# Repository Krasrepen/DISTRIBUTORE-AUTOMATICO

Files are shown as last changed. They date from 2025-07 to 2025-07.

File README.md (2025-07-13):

Distributore Automatico Intelligente - ESP32

📝 Descrizione del Progetto

Sistema automatizzato per la gestione e distribuzione di componenti industriali con controllo accessi RFID, monitoraggio inventario in tempo reale e integrazione Power Apps.

🎯 Caratteristiche Principali

Autenticazione RFID: Accesso controllato tramite badge personalizzati
Gestione Inventario: Tracciamento automatico componenti con celle di carico
Interfaccia Touch: Display Nextion 3.5" per controllo intuitivo
Automazione Cassetti: Apertura/chiusura motorizzata con stepper motors
Cloud Integration: Sincronizzazione dati con Microsoft Power Apps
Operazioni Multiple: Prelievo, rientro, rifornimento e gestione manuale

🛠️ Hardware Utilizzato
ESP32 DevKit V1
Display Nextion NX4832K035_011
RFID Reader RC522
2x NEMA 17 + TB6600
4x Celle di carico + HX711

📦 Prodotti Gestiti

Cassetto A: Rondelle (peso unitario: 13g)
Cassetto B: Viti M8 (peso unitario: 29g)

🚀 Funzionalità del Sistema
1. Autenticazione e Sicurezza

Badge RFID univoci per ogni utente autorizzato
Timeout automatico sessioni (2 minuti)
Controllo accessi centralizzato

2. Operazioni Supportate

PRELIEVO: Ritiro componenti con aggiornamento automatico inventario
RIENTRO: Restituzione componenti precedentemente prelevati
RIFORNIMENTO: Aggiunta nuovi stock al magazzino
CHIUSURA MANUALE: Controllo manuale apertura cassetti

3. Monitoraggio Intelligente

Conteggio automatico tramite peso (precisione ±1 pezzo)
Calcolo quantità disponibili in tempo reale
Soglie minime personalizzabili per ogni prodotto

4. Integrazione Cloud

Sincronizzazione bidirezionale con Power Apps
Tracciabilità completa operazioni (chi, cosa, quando)
Dashboard analytics e reporting

📋 Schema Database Power Apps
Tabelle Principali:

Componenti: Anagrafica prodotti e quantità
Utenti: Gestione badge e autorizzazioni
Prelievo: Log operazioni di ritiro
Rientro: Log operazioni di restituzione
Rifornimento: Log operazioni di ricarica stock
Fornitori: Anagrafica fornitori componenti

🔧 Setup e Installazione
Prerequisiti

Arduino IDE 1.8.19+
Librerie: MFRC522, HX711, WiFi, HTTPClient, ArduinoJson
Account Microsoft Power Platform

Configurazione Hardware

Collegare componenti secondo pinout fornito
Calibrare celle di carico per ogni cassetto
Configurare display Nextion con file HMI

Configurazione Software

Compilare e caricare sketch Arduino
Configurare credenziali WiFi nel codice
Impostare webhook Power Automate
Registrare badge RFID utenti autorizzati

📊 Pinout ESP32

// RFID RC522
RST: 15, IRQ: 2, MISO: 4, SCK: 17, MOSI: 16, SS: 5

// MOTORI STEPPER  
Motore A: Enable=18, PUL=19, Dir=21
Motore B: Enable=22, PUL=23, Dir=32

// DISPLAY NEXTION
RX=35, TX=14

// CELLE DI CARICO
Cassetto A: DT=33, SCK=25  
Cassetto B: DT=26, SCK=27

🎮 Interfaccia Utente
Flusso Operativo:

Schermata Benvenuto: Richiesta badge RFID
Menu Operazioni: Selezione tipo operazione
Selezione Prodotto: Scelta componente da gestire
Operazione in Corso: Monitoraggio real-time peso/quantità
Conferma: Completamento e aggiornamento inventario

Indicatori Stato:

🟢 LED Verde: Utente autenticato
🔵 LED Blu: Connessione WiFi attiva
📊 Progress Bar: Quantità disponibili (0-30 pezzi)
⚖️ Display Peso: Peso attuale cassetto (±0.1g)

💡 Applicazioni Pratiche

Magazzini Industriali: Gestione componenti elettronici/meccanici
Laboratori R&D: Controllo materiali e strumentazione
Officine Meccaniche: Distribuzione utensili e ricambi
Ambiente Produttivo: Tracciabilità materiali per qualità

🛡️ Sicurezza e Affidabilità

Calibrazione automatica celle di carico con backup EEPROM
Gestione errori e valori anomali sensori
Retry automatico comunicazioni Power Apps
Protezione da sovraccarichi motori

📈 Vantaggi Business

Riduzione Sprechi: Tracciabilità completa prelievi
Ottimizzazione Stock: Monitoraggio automatico soglie minime
Controllo Accessi: Solo personale autorizzato
Audit Trail: Log completo per conformità ISO
ROI Rapido: Automazione processo manuale

🔮 Sviluppi Futuri

 Supporto multi-cassetto (espandibile a 8 cassetti)
 App mobile companion per gestione remota
 Integrazione bilancia di precisione esterna
 Sistema di backup locale su SD card
 Notifiche push per soglie minime raggiunte

📞 Supporto
Per questioni tecniche o richieste di personalizzazione, contattare il team di sviluppo.

Versione: 2.0
Ultimo aggiornamento: Luglio 2025
Licenza: ITS Academy Udine
Autore: Michele Zago
Email: zago.michele2002@gmail.com

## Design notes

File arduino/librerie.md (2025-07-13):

1. MFRC522 (Lettore RFID)

Versione: 1.4.10 o superiore
Autore: GithubCommunity
Scopo: Gestione lettore RFID RC522
Installazione: Library Manager → Cerca "MFRC522"

2. HX711 (Celle di carico)

Versione: 0.7.5 o superiore
Autore: Rob Tillaart
Scopo: Interfaccia con amplificatori celle di carico
Installazione: Library Manager → Cerca "HX711 Arduino Library"

3. ArduinoJson (Gestione JSON)

Versione: 6.19.4 o superiore
Autore: Benoit Blanchon
Scopo: Parsing/creazione messaggi JSON per Power Apps
Installazione: Library Manager → Cerca "ArduinoJson"

4. WiFi (Connettività)

Versione: Inclusa in ESP32 Core
Scopo: Connessione WiFi per comunicazione Power Apps
Installazione: ✅ Automatica con ESP32 board package

5. HTTPClient (Richieste HTTP)

Versione: Inclusa in ESP32 Core
Scopo: Invio webhook a Power Automate
Installazione: ✅ Automatica con ESP32 board package

6. SPI (Comunicazione seriale)

Versione: Inclusa in Arduino Core
Scopo: Comunicazione con RFID RC522
Installazione: ✅ Automatica

7. EEPROM (Memoria permanente)

Versione: Inclusa in ESP32 Core
Scopo: Salvataggio fattori calibrazione celle
Installazione: ✅ Automatica con ESP32 board package

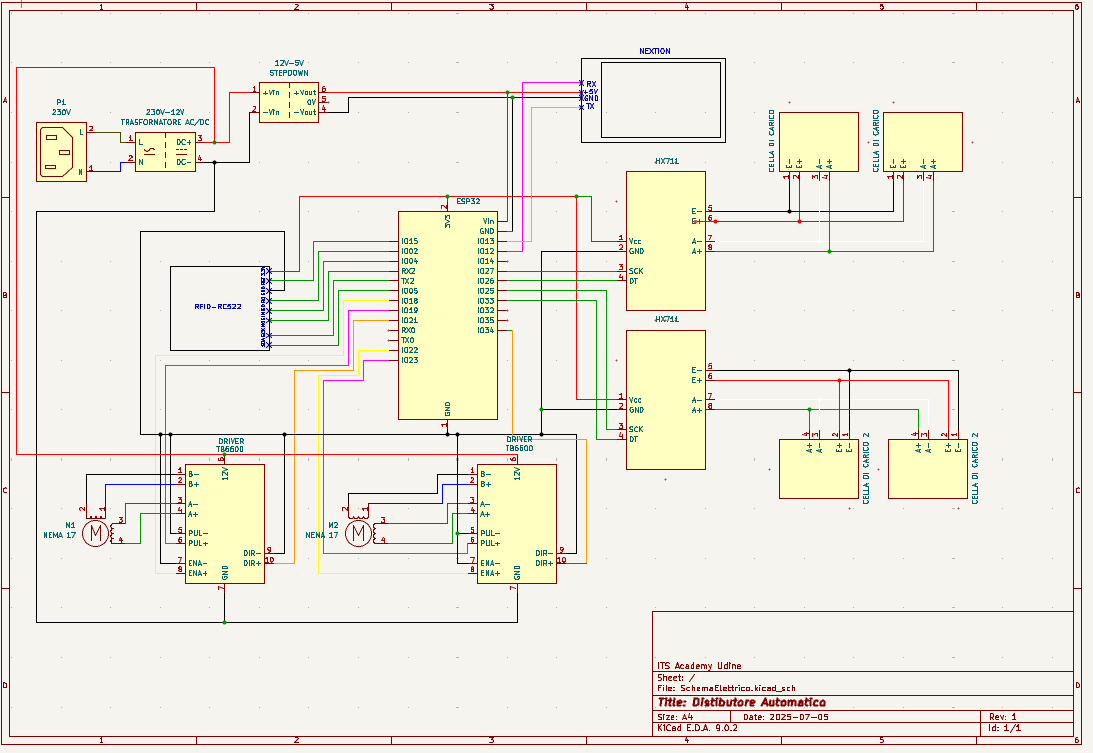
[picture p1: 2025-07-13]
schema elettrico/SchemaElettricoScreen.png

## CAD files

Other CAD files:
inventor/AssiemeGiusto.iam
inventor/Base1.ipt
inventor/Base2.ipt
inventor/Coperchi1.ipt
inventor/Coperchio.ipt
inventor/Coperchio2.ipt
inventor/EsplosoGiusto.ipn
inventor/Nextion1.ipt
inventor/Nextion2.ipt
inventor/ParteCassetto.ipt
inventor/Parte_frontale.ipt
inventor/PiattoBilancia.ipt
inventor/PortaCassetto1.ipt
inventor/Porticina.ipt
inventor/Porticina11.ipt
inventor/Porticina22.ipt

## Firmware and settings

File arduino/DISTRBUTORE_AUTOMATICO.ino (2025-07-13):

#include <SPI.h>
#include <MFRC522.h>
#include <HX711.h>
#include <WiFi.h>
#include <HTTPClient.h>
#include <ArduinoJson.h>
#include <EEPROM.h>

// ============ PIN  ============
#define RST_PIN     15
#define IRQ_PIN     2   
#define MISO_PIN    4   
#define SCK_PIN     17  
#define MOSI_PIN    16  
#define SS_PIN      5   
#define NEXTION_RX  35
#define NEXTION_TX  14
#define MOTOR_A_ENABLE  18
#define MOTOR_A_STEP    19
#define MOTOR_A_DIR     21
#define MOTOR_B_ENABLE  22
#define MOTOR_B_STEP    23
#define MOTOR_B_DIR     32

// PIN CELLE CORRETTI
#define LOADCELL_A_DOUT 33  // Cassetto A (Rondelle)
#define LOADCELL_A_SCK  25  // Cassetto A (Rondelle)
#define LOADCELL_B_DOUT 26  // Cassetto B (Viti M8)
#define LOADCELL_B_SCK  27  // Cassetto B (Viti M8)

// ============ EEPROM LAYOUT ============
#define EEPROM_SIZE         512
#define ADDR_CALIBRATION_A  0   
#define ADDR_CALIBRATION_B  4   
#define ADDR_OFFSET_A       8   
#define ADDR_OFFSET_B       12  
#define ADDR_INVENTARIO     16  

// ============ CONFIGURAZIONE ============
#define STEPS_PER_REVOLUTION 200
#define MICROSTEP 16              
#define STEPS_TOTALI (STEPS_PER_REVOLUTION * MICROSTEP)  
#define GIRI_APERTURA 1.5
#define STEPS_APERTURA (int)(STEPS_TOTALI * GIRI_APERTURA)  
#define VELOCITA_DELAY 800        
#define TIMEOUT_AUTENTICAZIONE 120000

// ============ WIFI ============
const char* ssid = "ZAGOTRAM";
const char* password = "Coccodrillo1965";
const char* POWER_AUTOMATE_WEBHOOK = "https://prod-03.northeurope.logic.azure.com:443/workflows/ae3270c48d93463dbcd42e71d0d0e2c0/triggers/manual/paths/invoke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";

// ============ STRUTTURE ============
struct Prodotto {
  String nome;
  int quantita;
  float pesoUnitario;
  int sogliaMinima;
};

struct Utente {
  byte uid[4];
  String nome;
  String cognome;
  String codiceBadge;
  bool autorizzato;
};

enum TipoOperazione { PRELIEVO, RIENTRO, RIFORNIMENTO, CHIUSURA_MANUALE };
enum StatoSistema { NON_AUTENTICATO, SELEZIONE_OPERAZIONE, SELEZIONE_PRODOTTO, OPERAZIONE_IN_CORSO, COMPLETATO };

// ============ VARIABILI GLOBALI ============
MFRC522 rfid(SS_PIN, RST_PIN);
HX711 scalaA, scalaB;

// *** FATTORI CALIBRAZIONE VERI ***
float fattoreCalibrazioneA = 1.0;
float fattoreCalibrazioneB = 1.0;
long offsetA = 0;
long offsetB = 0;
bool calibrazioneValidaA = false;
bool calibrazioneValidaB = false;

StatoSistema statoCorrente = NON_AUTENTICATO;
TipoOperazione operazioneCorrente;
bool utenteAutenticato = false;
unsigned long tempoAutenticazione = 0;
String nomeUtenteCorrente = "";
String cognomeUtenteCorrente = "";
String codiceBadgeCorrente = "";
int prodottoSelezionato = -1;
bool cassetto[2] = {false, false}; 
int cassettoCorrente = -1;
volatile int posizioneCorrente[2] = {0, 0};
volatile bool motoreAttivo = false;

// Pesi
float pesoA = 0, pesoB = 0;
float pesoIniziale = 0;

// *** VARIABILI PER WARNING E DISABILITAZIONE BOTTONE ***
bool bottoneConfermaDisabilitato = false;
unsigned long ultimoWarning = 0;

// Database
Prodotto prodotti[2] = {
  {"Rondella", 50, 13.0, 5},
  {"Vite M8", 100, 29.0, 3}
};

Utente utentiAutorizzati[] = {
  {{0xAC, 0xE8, 0x2C, 0x23}, "Michele", "Zago", "BADGE-001", true},
  {{0xB3, 0x8B, 0x1D, 0x40}, "Pietro", "Zago", "BADGE-002", true},
  {{0xAA, 0xBB, 0xCC, 0xDD}, "Admin", "System", "BADGE-000", true}
};

bool nextionDisponibile = false;

// ============================================================================
// 🚀 SETUP CON CARICAMENTO FATTORI VERI DA EEPROM
// ============================================================================

void setup() {
  Serial.begin(115200);
  delay(1000);
  
  EEPROM.begin(EEPROM_SIZE);
  configuraPinMotori();
  inizializzaRFID();
  
  caricaFattoriCalibrazioneVeri();
  inizializzaCelleConFattoriVeri();
  
  inizializzaNextion();
  setupWiFi();
  
  testSistemaConFattoriVeri();
  
  delay(2000);
  inviaInventarioInizialeAPowerApps();
}

// ============================================================================
// 🔧 CARICA FATTORI VERI DA EEPROM
// ============================================================================

void caricaFattoriCalibrazioneVeri() {
  float tempFactorA, tempFactorB;
  long tempOffsetA, tempOffsetB;
  
  EEPROM.get(ADDR_CALIBRATION_A, tempFactorA);
  EEPROM.get(ADDR_CALIBRATION_B, tempFactorB);
  EEPROM.get(ADDR_OFFSET_A, tempOffsetA);
  EEPROM.get(ADDR_OFFSET_B, tempOffsetB);
  
  // Verifica validità Cassetto A
  if (!isnan(tempFactorA) && tempFactorA > 0.1 && tempFactorA < 100000) {
    fattoreCalibrazioneA = tempFactorA;
    offsetA = tempOffsetA;
    calibrazioneValidaA = true;
  } else {
    calibrazioneValidaA = true;
    fattoreCalibrazioneA = -522.15f; 
    offsetA = 169002; 
  }
  
  // Verifica validità Cassetto B
  if (!isnan(tempFactorB) && tempFactorB > 0.1 && tempFactorB < 100000) {
    fattoreCalibrazioneB = tempFactorB;
    offsetB = tempOffsetB;
    calibrazioneValidaB = true;
  } else {
    calibrazioneValidaB = true;
    fattoreCalibrazioneB = -518.97f; 
    offsetB = 293020; 
  }
}

void inizializzaCelleConFattoriVeri() {
  scalaA.begin(LOADCELL_A_DOUT, LOADCELL_A_SCK);
  scalaB.begin(LOADCELL_B_DOUT, LOADCELL_B_SCK);
  
  delay(1000);
  
  bool connessioneA = scalaA.is_ready();
  bool connessioneB = scalaB.is_ready();
  
  if (connessioneA) {
    scalaA.set_scale(fattoreCalibrazioneA);
    scalaA.set_offset(offsetA);
  }
  
  if (connessioneB) {
    scalaB.set_scale(fattoreCalibrazioneB);
    scalaB.set_offset(offsetB);
  }
}

void testSistemaConFattoriVeri() {
  if (scalaA.is_ready()) {
    float pesoTestA = scalaA.get_units(3);
  }
  
  if (scalaB.is_ready()) {
    float pesoTestB = scalaB.get_units(3);
  }
}

// ============================================================================
// ⚖️ LETTURA PESI CON FATTORI VERI
// ============================================================================

void aggiornaPesi() {
  static unsigned long ultimoAggiornamento = 0;
  
  if (millis() - ultimoAggiornamento > 1000) {
    
    // Cassetto A
    if (scalaA.is_ready()) {
      float peso_raw = scalaA.get_units(2);
      
      if (abs(peso_raw) < 10000 && !isnan(peso_raw) && !isinf(peso_raw)) {
        pesoA = peso_raw;
      } else {
        pesoA = 0;
      }
      
      if (abs(pesoA) < 0.5) pesoA = 0;
    } else {
      pesoA = 0;
    }
    
    // Cassetto B
    if (scalaB.is_ready()) {
      float peso_raw = scalaB.get_units(2);
      
      if (abs(peso_raw) < 10000 && !isnan(peso_raw) && !isinf(peso_raw)) {
        pesoB = peso_raw;
      } else {
        pesoB = 0;
      }
      
      if (abs(pesoB) < 0.5) pesoB = 0;
    } else {
      pesoB = 0;
    }
    
    ultimoAggiornamento = millis();
  }
}

// ============================================================================
// 🔧 CALCOLO PEZZI CON SEGNO CORRETTO
// ============================================================================

int calcolaPezziConSegno(float pesoDifferenza, int prodottoIndex, TipoOperazione operazione) {
  if (abs(pesoDifferenza) < 0.1) return 0;
  
  int pezziBase = (int)round(abs(pesoDifferenza) / prodotti[prodottoIndex].pesoUnitario);
  
  switch (operazione) {
    case PRELIEVO:
      return (pesoDifferenza < 0) ? pezziBase : -pezziBase;
      
    case RIENTRO:
    case RIFORNIMENTO:
      return (pesoDifferenza > 0) ? pezziBase : -pezziBase;
      
    default:
      return 0;
  }
}

// ============================================================================
// 🚨 CONTROLLO CONTINUO OPERAZIONI AL CONTRARIO CON DISABILITAZIONE BOTTONE
// ============================================================================

void controllaOperazioneAlContrario() {
  if (statoCorrente != OPERAZIONE_IN_CORSO || prodottoSelezionato == -1 || cassettoCorrente == -1) {
    return;
  }
  
  float pesoCorrente = (cassettoCorrente == 0) ? pesoA : pesoB;
  float pesoDifferenza = pesoCorrente - pesoIniziale;
  bool calibrazioneValida = (cassettoCorrente == 0) ? calibrazioneValidaA : calibrazioneValidaB;
  
  if (!calibrazioneValida) return;
  
  float sogliaMinima = prodotti[prodottoSelezionato].pesoUnitario * 0.2;
  
  bool operazioneAlContrario = false;
  String messaggioWarning = "";
  
  if (abs(pesoDifferenza) >= sogliaMinima) {
    int componentiModificati = calcolaPezziConSegno(pesoDifferenza, prodottoSelezionato, operazioneCorrente);
    
    switch(operazioneCorrente) {
      case PRELIEVO:
        if (componentiModificati < 0) {
          operazioneAlContrario = true;
          messaggioWarning = "AVVISO: STAI AGGIUNGENDO!";
        }
        break;
        
      case RIENTRO:
        if (componentiModificati < 0) {
          operazioneAlContrario = true;
          messaggioWarning = "AVVISO: STAI TOGLIENDO!";
        }
        break;
        
      case RIFORNIMENTO:
        if (componentiModificati < 0) {
          operazioneAlContrario = true;
          messaggioWarning = "AVVISO: STAI TOGLIENDO!";
        }
        break;
    }
  }
  
  if (operazioneAlContrario && !bottoneConfermaDisabilitato) {
    bottoneConfermaDisabilitato = true;
    ultimoWarning = millis();
    
    inviaComandoNextion("b0.en=0");
    inviaComandoNextion("b0.bco=63488");
    
    inviaComandoNextion("t1.txt=\"" + messaggioWarning + "\"");
    inviaComandoNextion("t1.pco=63488");
    
  } else if (!operazioneAlContrario && bottoneConfermaDisabilitato) {
    bottoneConfermaDisabilitato = false;
    
    inviaComandoNextion("b0.en=1");
    inviaComandoNextion("b0.bco=2016");
    
    inviaComandoNextion("t1.txt=\"" + prodotti[prodottoSelezionato].nome + "\"");
    inviaComandoNextion("t1.pco=65535");
  }
  
  if (bottoneConfermaDisabilitato && (millis() - ultimoWarning > 3000)) {
    ultimoWarning = millis();
    inviaComandoNextion("t1.txt=\"" + messaggioWarning + "\"");
  }
}

// ============================================================================
// 🔧 LOOP PRINCIPALE
// ============================================================================

void loop() {
  if (rfid.PICC_IsNewCardPresent() && rfid.PICC_ReadCardSerial()) {
    gestisciRFID();
  }
  
  if (Serial2.available()) {
    gestisciComandoNextion();
  }
  
  aggiornaPesi();
  
  if (utenteAutenticato) {
    verificaTimeout();
  }
  
  static unsigned long ultimoDisplayUpdate = 0;
  if (millis() - ultimoDisplayUpdate > 1000) {
    if (statoCorrente == OPERAZIONE_IN_CORSO) {
      aggiornaDisplayNextion();
    }
    ultimoDisplayUpdate = millis();
  }
  
  delay(50);
}

// ============ INIZIALIZZAZIONE COMPONENTI ============

void configuraPinMotori() {
  pinMode(MOTOR_A_ENABLE, OUTPUT);
  pinMode(MOTOR_A_STEP, OUTPUT);
  pinMode(MOTOR_A_DIR, OUTPUT);
  digitalWrite(MOTOR_A_ENABLE, HIGH);
  
  pinMode(MOTOR_B_ENABLE, OUTPUT);
  pinMode(MOTOR_B_STEP, OUTPUT);
  pinMode(MOTOR_B_DIR, OUTPUT);
  digitalWrite(MOTOR_B_ENABLE, HIGH);
}

void inizializzaRFID() {
  SPI.begin(SCK_PIN, MISO_PIN, MOSI_PIN, SS_PIN);
  rfid.PCD_Init();
}

void inizializzaNextion() {
  Serial2.begin(9600, SERIAL_8N1, NEXTION_RX, NEXTION_TX);
  delay(500);
  
  Serial2.print("rest");
  Serial2.write(0xff);
  Serial2.write(0xff);
  Serial2.write(0xff);
  delay(3000);
  
  inviaComandoNextion("page 0");
  inviaComandoNextion("t0.txt=\"DISTRIBUTORE AUTOMATICO\"");
  inviaComandoNextion("t1.txt=\"Avvicina carta RFID\"");
  inviaComandoNextion("b0.val=0");
  inviaComandoNextion("b1.val=0");
  
  nextionDisponibile = true;
}

void setupWiFi() {
  WiFi.begin(ssid, password);
  
  int tentativi = 0;
  while (WiFi.status() != WL_CONNECTED && tentativi < 8) {
    delay(1000);
    tentativi++;
  }
  
  if (WiFi.status() == WL_CONNECTED) {
    inviaComandoNextion("b1.val=1");
  }
}

void inviaComandoNextion(String comando) {
  if (!nextionDisponibile) return;
  
  Serial2.print(comando);
  Serial2.write(0xff);
  Serial2.write(0xff);
  Serial2.write(0xff);
  delay(50);
}

// ============ NEXTION ============

void gestisciComandoNextion() {
  String comando = "";
  
  unsigned long timeout = millis() + 100;
  while (Serial2.available() && millis() < timeout) {
    char c = Serial2.read();
    if (c == 0xFF) {
      if (Serial2.available() >= 2) {
        char c1 = Serial2.read();
        char c2 = Serial2.read();
        if (c1 == 0xFF && c2 == 0xFF) break;
      }
    } else if (c >= 32 && c <= 126) {
      comando += c;
    }
  }
  
  if (comando.length() > 0) {
    processaComandoNextion(comando);
  }
}

void processaComandoNextion(String cmd) {
  if (cmd == "op0") selezionaOperazione(0);
  else if (cmd == "op1") selezionaOperazione(1);
  else if (cmd == "op2") selezionaOperazione(2);
  else if (cmd == "op3") selezionaOperazione(3);
  else if (cmd == "prod0") selezionaProdotto(0);
  else if (cmd == "prod1") selezionaProdotto(1);
  else if (cmd == "conferma") confermaOperazione();
  else if (cmd == "annulla") annullaOperazione();
  else if (cmd == "logout") logout();
  else if (cmd == "b4") logout();
  else if (cmd == "back") {
    if (statoCorrente == SELEZIONE_PRODOTTO) {
      statoCorrente = SELEZIONE_OPERAZIONE;
      aggiornaDisplayLogin();
    }
  }
}

// ============ RFID ============

void gestisciRFID() {
  static unsigned long ultimaAutenticazione = 0;
  
  if (millis() - ultimaAutenticazione < 1000) {
    rfid.PICC_HaltA();
    rfid.PCD_StopCrypto1();
    return;
  }
  
  Utente* utente = verificaUtente();
  
  if (utenteAutenticato && utente != nullptr) {
    if (statoCorrente == NON_AUTENTICATO) {
      utenteAutenticato = false;
      nomeUtenteCorrente = "";
      cognomeUtenteCorrente = "";
      codiceBadgeCorrente = "";
      tempoAutenticazione = 0;
    }
  }
  
  if (utente != nullptr && !utenteAutenticato) {  
    utenteAutenticato = true;
    tempoAutenticazione = millis();
    ultimaAutenticazione = millis();
    nomeUtenteCorrente = utente->nome;
    cognomeUtenteCorrente = utente->cognome;
    codiceBadgeCorrente = utente->codiceBadge;
    statoCorrente = SELEZIONE_OPERAZIONE;
    
    inviaComandoNextion("page 1");
    delay(1000);
    
    inviaComandoNextion("b0.val=1");
    delay(100);
    
    inviaComandoNextion("t0.txt=\"Benvenuto " + nomeUtenteCorrente + "\"");
    delay(100);
    
    inviaComandoNextion("t1.txt=\"Seleziona operazione\"");
    delay(100);
    
  } else if (utente != nullptr && utenteAutenticato) {
    tempoAutenticazione = millis();
    ultimaAutenticazione = millis();
    
  } else {
    ultimaAutenticazione = millis();
    inviaComandoNextion("t0.txt=\"ACCESSO NEGATO\"");
    inviaComandoNextion("t1.txt=\"Badge non autorizzato\"");
    delay(2000);
    inviaComandoNextion("t0.txt=\"DISTRIBUTORE AUTOMATICO\"");
    inviaComandoNextion("t1.txt=\"Avvicina carta RFID\"");
  }
  
  rfid.PICC_HaltA();
  rfid.PCD_StopCrypto1();
}

Utente* verificaUtente() {
  for (int i = 0; i < sizeof(utentiAutorizzati) / sizeof(utentiAutorizzati[0]); i++) {
    bool uidCorrispondente = true;
    
    for (byte j = 0; j < rfid.uid.size && j < 4; j++) {
      if (rfid.uid.uidByte[j] != utentiAutorizzati[i].uid[j]) {
        uidCorrispondente = false;
        break;
      }
    }
    
    if (uidCorrispondente && utentiAutorizzati[i].autorizzato) {
      return &utentiAutorizzati[i];
    }
  }
  return nullptr;
}

void verificaTimeout() {
  if (utenteAutenticato && (millis() - tempoAutenticazione > TIMEOUT_AUTENTICAZIONE)) {
    logout();
  }
}

void logout() {
  utenteAutenticato = false;
  nomeUtenteCorrente = "";
  cognomeUtenteCorrente = "";
  codiceBadgeCorrente = "";
  statoCorrente = NON_AUTENTICATO;
  tempoAutenticazione = 0;
  
  bottoneConfermaDisabilitato = false;
  ultimoWarning = 0;
  
  rfid.PICC_HaltA();
  rfid.PCD_StopCrypto1();
  delay(100);
  
  for (int i = 0; i < 2; i++) {
    if (cassetto[i]) {
      chiudiCassetto(i);
    }
  }
  
  prodottoSelezionato = -1;
  cassettoCorrente = -1;
  
  inviaComandoNextion("page 0");
  delay(1000);
  
  inviaComandoNextion("t0.txt=\"DISTRIBUTORE AUTOMATICO\"");
  delay(200);
  
  inviaComandoNextion("t1.txt=\"Avvicina carta RFID\"");
  delay(200);
  
  inviaComandoNextion("b0.val=0");
  delay(200);
  
  delay(1000);
}

// ============ OPERAZIONI ============

void selezionaOperazione(int op) {
  if (!utenteAutenticato) return;
  
  operazioneCorrente = (TipoOperazione)op;
  String nomiOperazioni[] = {"PRELIEVO", "RIENTRO", "RIFORNIMENTO", "CHIUSURA MANUALE"};
  
  if (operazioneCorrente == CHIUSURA_MANUALE) {
    for (int i = 0; i < 2; i++) {
      if (cassetto[i]) {
        chiudiCassetto(i);
      }
    }
    inviaComandoNextion("t0.txt=\"Cassetti chiusi\"");
    delay(2000);
    aggiornaDisplayLogin();
  } else {
    statoCorrente = SELEZIONE_PRODOTTO;
    inviaComandoNextion("page 2");
    delay(500);
    inviaComandoNextion("t0.txt=\"" + nomiOperazioni[op] + "\"");
    inviaComandoNextion("t1.txt=\"Seleziona prodotto\"");
    inviaComandoNextion("b2.txt=\"" + prodotti[0].nome + " (" + String(prodotti[0].quantita) + ")\"");
    inviaComandoNextion("b3.txt=\"" + prodotti[1].nome + " (" + String(prodotti[1].quantita) + ")\"");
  }
}

void selezionaProdotto(int prod) {
  if (!utenteAutenticato || prod < 0 || prod >= 2) return;
  
  prodottoSelezionato = prod;
  cassettoCorrente = prod;
  
  bottoneConfermaDisabilitato = false;
  ultimoWarning = 0;
  
  aggiornaPesi();
  delay(1000);
  
  pesoIniziale = (cassettoCorrente == 0) ? pesoA : pesoB;
  
  apriCassetto(cassettoCorrente);
  statoCorrente = OPERAZIONE_IN_CORSO;
  
  inviaComandoNextion("page 3");
  delay(500);
  
  String istruzioni = "";
  switch (operazioneCorrente) {
    case PRELIEVO: istruzioni = "PRELIEVO IN CORSO"; break;
    case RIENTRO: istruzioni = "RIENTRO IN CORSO"; break;
    case RIFORNIMENTO: istruzioni = "RIFORNIMENTO IN CORSO"; break;
  }
  
  inviaComandoNextion("t0.txt=\"" + istruzioni + "\"");
  inviaComandoNextion("t1.txt=\"" + prodotti[prod].nome + "\"");
  inviaComandoNextion("t2.txt=\"Peso: " + String(pesoIniziale, 1) + "g\"");
  inviaComandoNextion("t3.txt=\"0 (0)\"");
  inviaComandoNextion("j0.val=0");
  
  inviaComandoNextion("b0.en=1");
  inviaComandoNextion("b0.bco=2016");
}

void confermaOperazione() {
  if (!utenteAutenticato || prodottoSelezionato == -1 || cassettoCorrente == -1) return;
  
  if (bottoneConfermaDisabilitato) {
    inviaComandoNextion("t0.txt=\"CORREGGI OPERAZIONE\"");
    delay(1000);
    
    String istruzioni = "";
    switch (operazioneCorrente) {
      case PRELIEVO: istruzioni = "PRELIEVO IN CORSO"; break;
      case RIENTRO: istruzioni = "RIENTRO IN CORSO"; break;
      case RIFORNIMENTO: istruzioni = "RIFORNIMENTO IN CORSO"; break;
    }
    inviaComandoNextion("t0.txt=\"" + istruzioni + "\"");
    return;
  }
  
  aggiornaPesi();  
  delay(500);
  aggiornaPesi();  
  
  float pesoFinale = (cassettoCorrente == 0) ? pesoA : pesoB;
  float pesoDifferenza = pesoFinale - pesoIniziale;
  
  int componentiModificati = 0;
  bool operazioneValida = false;
  
  if ((cassettoCorrente == 0 && calibrazioneValidaA) || (cassettoCorrente == 1 && calibrazioneValidaB)) {
    
    float sogliaMinima = prodotti[prodottoSelezionato].pesoUnitario * 0.2;
    
    if (abs(pesoDifferenza) >= sogliaMinima) {
      componentiModificati = calcolaPezziConSegno(pesoDifferenza, prodottoSelezionato, operazioneCorrente);
      
      if (componentiModificati != 0) {
        operazioneValida = true;
        
        if (componentiModificati > 0) {
          if (operazioneCorrente == PRELIEVO) {
            prodotti[prodottoSelezionato].quantita -= componentiModificati;
          } else {
            prodotti[prodottoSelezionato].quantita += componentiModificati;
          }
        } else {
          if (operazioneCorrente == PRELIEVO) {
            prodotti[prodottoSelezionato].quantita -= componentiModificati;
          } else {
            prodotti[prodottoSelezionato].quantita += componentiModificati;
          }
        }
      }
    }
  }
  
  if (prodotti[prodottoSelezionato].quantita < 0) {
    prodotti[prodottoSelezionato].quantita = 0;
  }
  
  if (WiFi.status() == WL_CONNECTED && operazioneValida && componentiModificati != 0) {
    String tipoOp = "";
    switch (operazioneCorrente) {
      case PRELIEVO: tipoOp = "PRELIEVO"; break;
      case RIENTRO: tipoOp = "RIENTRO"; break;
      case RIFORNIMENTO: tipoOp = "RIFORNIMENTO"; break;
    }
    
    inviaAPowerAutomate(tipoOp, codiceBadgeCorrente, prodotti[prodottoSelezionato].nome, abs(componentiModificati), abs(pesoDifferenza));
  }
  
  chiudiCassetto(cassettoCorrente);
  
  inviaComandoNextion("page 1");
  if (abs(componentiModificati) > 0) {
    String messaggioFinale = "";
    if (componentiModificati > 0 && 
        ((operazioneCorrente == PRELIEVO) || 
         (operazioneCorrente == RIENTRO || operazioneCorrente == RIFORNIMENTO))) {
      String operazioneRichiesta = "";
      switch(operazioneCorrente) {
        case PRELIEVO: operazioneRichiesta = "PRELIEVO"; break;
        case RIENTRO: operazioneRichiesta = "RIENTRO"; break; 
        case RIFORNIMENTO: operazioneRichiesta = "RIFORNIMENTO"; break;
      }
      messaggioFinale = "OK " + operazioneRichiesta + ": " + String(abs(componentiModificati)) + " " + prodotti[prodottoSelezionato].nome;
    } else {
      messaggioFinale = "ERRORE: " + String(abs(componentiModificati)) + " " + prodotti[prodottoSelezionato].nome + " (inaspettato)";
    }
    inviaComandoNextion("t0.txt=\"Operazione completata\"");
    inviaComandoNextion("t1.txt=\"" + messaggioFinale + "\"");
  } else {
    inviaComandoNextion("t0.txt=\"Nessuna modifica\"");
    inviaComandoNextion("t1.txt=\"Peso invariato\"");
  }
  
  prodottoSelezionato = -1;
  cassettoCorrente = -1;
  statoCorrente = COMPLETATO;
  
  delay(3000);
  statoCorrente = SELEZIONE_OPERAZIONE;
  aggiornaDisplayLogin();
}
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

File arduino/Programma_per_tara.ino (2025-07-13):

#include <HX711.h>
#include <EEPROM.h>

// ============ CONFIGURAZIONE PIN ============
// Cassetto A: HX711 con 2 celle di carico collegate
#define LOADCELL_DOUT_A   33
#define LOADCELL_SCK_A    25

// Cassetto B: HX711 con 2 celle di carico collegate  
#define LOADCELL_DOUT_B   26
#define LOADCELL_SCK_B    27

// ============ CONFIGURAZIONE EEPROM ============
#define EEPROM_SIZE       512
#define ADDR_CALIBRATION_A  0   // Indirizzo per fattore calibrazione A
#define ADDR_CALIBRATION_B  4   // Indirizzo per fattore calibrazione B
#define ADDR_OFFSET_A      8   // Indirizzo per offset A
#define ADDR_OFFSET_B      12  // Indirizzo per offset B

// ============ VARIABILI GLOBALI ============
HX711 scalaA;  // Bilancia cassetto A (2 celle collegate)
HX711 scalaB;  // Bilancia cassetto B (2 celle collegate)

float fattoreCalibrazioneA = 1.0;
float fattoreCalibrazioneB = 1.0;
long offsetA = 0;
long offsetB = 0;

bool sistemaPronto = false;
bool calibrazioneCompletaA = false;
bool calibrazioneCompletaB = false;

// ============ SETUP ============
void setup() {
  Serial.begin(115200);
  delay(2000);
  
  Serial.println("\n╔══════════════════════════════════════════════════════════╗");
  Serial.println("║           🔧 CALIBRAZIONE CELLE DI CARICO ESP32          ║");
  Serial.println("║                    DISTRIBUTORE AUTOMATICO               ║");
  Serial.println("╠══════════════════════════════════════════════════════════╣");
  Serial.println("║  📦 Cassetto A: DT=33, SCK=25 (2 celle → 1 HX711)       ║");
  Serial.println("║  📦 Cassetto B: DT=26, SCK=27 (2 celle → 1 HX711)       ║");
  Serial.println("╚══════════════════════════════════════════════════════════╝\n");
  
  // Inizializza EEPROM
  EEPROM.begin(EEPROM_SIZE);
  Serial.println("💾 EEPROM inizializzata (" + String(EEPROM_SIZE) + " bytes)");
  
  // Inizializza le bilance
  Serial.println("🔄 Inizializzazione HX711...");
  
  scalaA.begin(LOADCELL_DOUT_A, LOADCELL_SCK_A);
  scalaB.begin(LOADCELL_DOUT_B, LOADCELL_SCK_B);
  
  delay(1000);
  
  // Verifica connessione
  Serial.print("📡 Test connessione Cassetto A... ");
  if (scalaA.is_ready()) {
    Serial.println("✅ OK");
  } else {
    Serial.println("❌ ERRORE - Verifica collegamenti!");
    return;
  }
  
  Serial.print("📡 Test connessione Cassetto B... ");
  if (scalaB.is_ready()) {
    Serial.println("✅ OK");
  } else {
    Serial.println("❌ ERRORE - Verifica collegamenti!");
    return;
  }
  
  // Carica calibrazioni salvate
  caricaCalibrazioni();
  
  sistemaPronto = true;
  
  Serial.println("\n✅ Sistema pronto per la calibrazione!");
  mostraMenu();
}

// ============ LOOP PRINCIPALE ============
void loop() {
  if (!sistemaPronto) {
    Serial.println("❌ Sistema non pronto. Riavvia ESP32.");
    delay(5000);
    return;
  }
  
  if (Serial.available()) {
    String comando = Serial.readStringUntil('\n');
    comando.trim();
    
    eseguiComando(comando);
  }
  
  delay(100);
}

// ============ GESTIONE COMANDI ============
void eseguiComando(String cmd) {
  cmd.toLowerCase();
  
  if (cmd == "menu") {
    mostraMenu();
  }
  else if (cmd == "status") {
    mostraStatus();
  }
  else if (cmd == "raw") {
    mostraValoriRaw();
  }
  else if (cmd == "peso") {
    mostraPesi();
  }
  else if (cmd == "tara_a") {
    taraCassettoA();
  }
  else if (cmd == "tara_b") {
    taraCassettoB();
  }
  else if (cmd == "tara_all") {
    taraTutto();
  }
  else if (cmd == "cal_a") {
    calibraCassettoA();
  }
  else if (cmd == "cal_b") {
    calibraCassettoB();
  }
  else if (cmd == "test_a") {
    testContinuoA();
  }
  else if (cmd == "test_b") {
    testContinuoB();
  }
  else if (cmd == "test_all") {
    testContinuoEntrambi();
  }
  else if (cmd == "save") {
    salvaCalibrazioni();
  }
  else if (cmd == "load") {
    caricaCalibrazioni();
  }
  else if (cmd == "reset") {
    resetCalibrazioni();
  }
  else if (cmd == "info") {
    mostraInfo();
  }
  else {
    Serial.println("❓ Comando non riconosciuto. Digita 'menu' per vedere i comandi disponibili.");
  }
}

// ============ MENU E STATUS ============
void mostraMenu() {
  Serial.println("\n╔══════════════════════════════════════════════════════════╗");
  Serial.println("║                    📋 MENU COMANDI                       ║");
  Serial.println("╠══════════════════════════════════════════════════════════╣");
  Serial.println("║  🔧 CALIBRAZIONE                                         ║");
  Serial.println("║    tara_a      - Tara Cassetto A (azzera)                ║");
  Serial.println("║    tara_b      - Tara Cassetto B (azzera)                ║");
  Serial.println("║    tara_all    - Tara entrambi i cassetti                ║");
  Serial.println("║    cal_a       - Calibra Cassetto A (peso noto)          ║");
  Serial.println("║    cal_b       - Calibra Cassetto B (peso noto)          ║");
  Serial.println("║                                                          ║");
  Serial.println("║  📊 MONITORAGGIO                                         ║");
  Serial.println("║    status      - Stato calibrazioni                      ║");
  Serial.println("║    raw         - Valori raw ADC                          ║");
  Serial.println("║    peso        - Pesi calibrati                          ║");
  Serial.println("║    test_a      - Test continuo Cassetto A (ESC per stop) ║");
  Serial.println("║    test_b      - Test continuo Cassetto B (ESC per stop) ║");
  Serial.println("║    test_all    - Test continuo entrambi (ESC per stop)   ║");
  Serial.println("║                                                          ║");
  Serial.println("║  💾 GESTIONE DATI                                        ║");
  Serial.println("║    save        - Salva calibrazioni in EEPROM            ║");
  Serial.println("║    load        - Carica calibrazioni da EEPROM           ║");
  Serial.println("║    reset       - Reset tutte le calibrazioni             ║");
  Serial.println("║    info        - Informazioni tecniche                   ║");
  Serial.println("╚══════════════════════════════════════════════════════════╝");
}
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
